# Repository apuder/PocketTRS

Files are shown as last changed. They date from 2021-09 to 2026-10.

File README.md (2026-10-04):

# PocketTRS

PocketTRS uses a modern microcontroller to emulate a TRS-80 personal computer. It can be connected to any compatible VGA monitor and PS/2 keyboard. PocketTRS has <a href="https://github.com/apuder/TRS-IO">TRS-IO</a> embedded for full FreHD support. PocketTRS offers the following features:

1. Emulates a Model III and Model 4
2. Grafyx support
3. Cassette input (500 baud only)
4. Game sound
5. Emulates the 50-pin expansion interface
6. Integrated <a href="https://github.com/apuder/TRS-IO">TRS-IO</a>

### Firmware

The heart of PocketTRS is an ESP32-based microcontroller. The firmware can be compiled using Espressif's ESP-IDF version 6.0. First install the
<a href="https://docs.espressif.com/projects/esp-idf/en/release-v6.0/esp32/get-started/index.html">ESP-IDF toolchain</a> for your platform. Next clone the PocketTRS git repository and compile the firmware via:

```
git clone --recursive https://github.com/apuder/PocketTRS.git
cd PocketTRS
idf.py build
```

The firmware can be flashed once the ESP as well as the necessary flashing circuitry is added to the PCB as explained in the next section.

### Hardware

This repository contains the complete KiCad and Gerber files for PocketTRS. The figure below shows the various connectors:



1. VGA connector
2. PS/2 connector
3. 3.5mm audio jack
4. Micro USB power supply
5. FTDI programmer interface
6. ESP reset button
7. Z80 reset button
8. 50-pin expansion interface

The BOM contains all required parts. Soldering surface mounted components can be tricky. It is suggested to build up the PCB in a particular order and test the board along each step. PocketTRS contains some test code that helps with the diagnostics. The test code can be activated at compile-time via `idf.py menuconfig > Component config > PocketTRS > Run PocketTRS PCB tests`. When the PCB tests are activated, diagnostics will be printed to the log that can be viewed via `idf.py -p <port> monitor`. The following steps refer to PocketTRS V2.3:

| Step | Components | Comments |
|---|---|---|
| 1 | J6, U4, C4, C5, C11 | Connect power via the Micro-USB adapter. Confirm 5V on J5, pin 5. Confirm 3.3V on U1, pin 2. Disconnect power. Note: for polarized caps the dot on the silkscreen indicates the positive terminal. |
| 2 | Q2, Q3, R12, R13, R14, R15, R16, C9, C10, J5, SW1, U1 | It should be possible to flash the ESP firmware via a FTDI adapter with these components. The log should print `MCP4361 not found`. |
| 3 | U5, C8 | Log should show `MCP4361 found` and `MCP23S17 not found`. Confirm 1V on pin 1, 2V on pin 2 and 3V on pin 3 of VGA adapter. |
| 4 | U2, U3, Q1, R10, R11, R17, C6, C7 | Log should show `MCP23S17 found` and `MCP23S08 found`. Measure the voltages of the odd pins of the 50-pin connector (except pin 45). The voltages should alternate between 0V and 5V every second. Permanent 0V indicates that a pin is not properly connected. A permanent 0.7V indicates that two neighboring pins are shorted. |
| 5 | J8, R18, R19, R20, R21 | Insert a formatted SD card into the SD card reader and press the 'PTRS RST' button after booting. The log should print `SD card succefully mounted`. |
| 6 | The rest | Solder the remaining components. First add the surface mounted components followed by the various connectors. |

### Usage

Once the PocketTRS card is assembled, connect a VGA monitor, a PS/2 keyboard and optinally a speaker to the audio jack. Power up PocketTRS via the micro-USB connector. You should see the TRS-80 `Cass?` prompt on the monitor. After booting PocketTRS, the following hotkeys are available via the PS/2 keyboard:

* &lt;F4&gt;  - Enable lowercase
* &lt;F5&gt;  - PocketTRS Configuration
* &lt;F6&gt;  - Send screenshot to the printer
* &lt;F9&gt;  - Reset Z80
* &lt;ESC&gt; - TRS-80 &lt;BREAK&gt; key
* '\\'         - TRS-80 &lt;CLEAR&gt; key

Instead of a PS/2 keyboard, a Bluetooth keyboard (Bluetooth Low Energy) can be used. It is paired in the web interface
(<a href="trs-io.local">trs-io.local</a>, Settings, Bluetooth Keyboard): put the keyboard in pairing mode, press *Scan* and then *Pair*
next to the keyboard's name. From then on the keyboard connects by itself.

&lt;F5&gt; allows the configuration of various aspects of PocketTRS, including setting up Wifi credentials and TRS-IO. Once Wifi is setup, the printer interface can be accessed via <a href="trs-io.local/printer">trs-io.local/printer</a>.

Use the configuration settings to activate TRS-IO. Alternatively it is possible to connect an external TRS-IO/FreHD card via the 50-pin expansion interface. In that case make sure that the internal TRS-IO is disabled.

For game sound, simply connect a speaker to the 3.5mm audio jack. It is also possible to load programs via the cassette interface (500 baud only). At the `Cass?` prompt hit 'L', connect PocketTRS audio jack to a laptop or smartphone, type `CLOAD` or `SYSTEM` in BASIC and play the 500 Baud audio file. You should see the blinking asterick in the top right corner.

### Showcases

The video below shows PocketTRS connected to a <a href="https://github.com/lambdamikel/Talker-80">Talker/80 card</a>:

PocketTRS connected to Talker/80 (https://www.youtube.com/watch?v=__6tL8iR-zk)

The next video shows PocketTRS booting from an external FreHD. Note that PocketTRS integrates TRS-IO and therefore also is compatible with FreHD, but
for the purpose of the demo, the internal TRS-IO is disabled:

PocketTRS connected to FreHD (https://www.youtube.com/watch?v=2HQh5efB2vM)

The following video shows PocketTRS booting from a 12 MB Tandy Hard Disk 26-4152 via XROM. PocketTRS is configured to disable
the internal TRS-IO and to use XROM:

PocketTRS booting from external HD (https://www.youtube.com/watch?v=oDgECPzYius)

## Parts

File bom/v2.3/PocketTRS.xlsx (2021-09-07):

PocketTRS V2.3 BOM
 |  |  |  |  |  | Previous
Reference Designator |  | Quantity | Package | Digi-Key Part Number | Manufacturer Part Number | Digi-Key Part Number | Manufacturer Part Number
C1 | 10uf | 1 | 1206 | 1276-1853-1-ND | CL31F106ZPHNNNE | 478-10742-1-ND | TAJA106K006SNJ | Changed to Ceramic / Non-Polarized
C2 | 10uf | 1 | 1206 | 1276-1853-1-ND | CL31F106ZPHNNNE | 478-10742-1-ND | TAJA106K006SNJ | Changed to Ceramic / Non-Polarized
C3 | 100n | 1 | 0805 | 399-9158-1-ND | C0805C104Z3VACTU
C4 | 100uf | 1 | 1206 | 1276-1782-1-ND | CAP CER 100UF 6.3V X5R 1206 | 478-8152-1-ND | F930J107KAA | Changed to Ceramic / Non-Polarized
C5 | 100uf | 1 | 1206 | 1276-1782-1-ND | CAP CER 100UF 6.3V X5R 1206 | 478-8152-1-ND | F930J107KAA | Changed to Ceramic / Non-Polarized
C6 | 100n | 1 | 0805 | 399-9158-1-ND | C0805C104Z3VACTU
C7 | 100n | 1 | 0805 | 399-9158-1-ND | C0805C104Z3VACTU
C8 | 100n | 1 | 0805 | 399-9158-1-ND | C0805C104Z3VACTU
C9 | 100n | 1 | 0805 | 399-9158-1-ND | C0805C104Z3VACTU
C10 | 100n | 1 | 0805 | 399-9158-1-ND | C0805C104Z3VACTU
C11 | 10uf | 1 | 1206 | 1276-1853-1-ND | CL31F106ZPHNNNE |  |  | New
C12 | 1uf | 1 | 1206 | 1276-1783-1-ND | CL31B105KOFNNNE |  |  | New
Q1 | BSS138 | 1 | SOT-23-3 | BSS138CT-ND | BSS138
Q2 | MMBT3904 | 1 | SOT-23-3 | MMBT3904-FDICT-ND | MMBT3904-7-F
Q3 | MMBT3904 | 1 | SOT-23-3 | MMBT3904-FDICT-ND | MMBT3904-7-F
R4 | 2K | 1 | 0805 | 311-2.00KCRCT-ND | RC0805FR-072KL
R5 | 2K | 1 | 0805 | 311-2.00KCRCT-ND | RC0805FR-072KL
R6 | 4K7 | 1 | 0805 | 311-4.70KCRCT-ND | RC0805FR-074K7L
R7 | 4K7 | 1 | 0805 | 311-4.70KCRCT-ND | RC0805FR-074K7L
R8 | 270R | 1 | 0805 | RHM270KCT-ND | ESR10EZPJ271
R9 | 150R | 1 | 0805 | RNCP0805FTD150RCT-ND | RNCP0805FTD150R
R10 | 10K | 1 | 0805 | 311-10.0KCRCT-ND | RC0805FR-0710KL
R11 | 10K | 1 | 0805 | 311-10.0KCRCT-ND | RC0805FR-0710KL
R12 | 4K7 | 1 | 0805 | 311-4.70KCRCT-ND | RC0805FR-074K7L
R13 | 4K7 | 1 | 0805 | 311-4.70KCRCT-ND | RC0805FR-074K7L
R14 | 12K | 1 | 0805 | A129762CT-ND | CRGCQ0805F12K
R15 | 12K | 1 | 0805 | A129762CT-ND | CRGCQ0805F12K
R16 | 4K7 | 1 | 0805 | 311-4.70KCRCT-ND | RC0805FR-074K7L
R17 | 10K | 1 | 0805 | 311-10.0KCRCT-ND | RC0805FR-0710KL
R18 | 10K | 1 | 0805 | 311-10.0KCRCT-ND | RC0805FR-0710KL
R19 | 10K | 1 | 0805 | 311-10.0KCRCT-ND | RC0805FR-0710KL
R20 | 10K | 1 | 0805 | 311-10.0KCRCT-ND | RC0805FR-0710KL
R21 | 10K | 1 | 0805 | 311-10.0KCRCT-ND | RC0805FR-0710KL
U1 | ESP32-WROVER-B | 1 |  | 1904-1034-1-ND | ESP32-WROVER-B (8MB)
U2 | MCP23S17 | 1 | SSOP | MCP23S17T-E/SSCT-ND | MCP23S17T-E/SS
U3 | MCP23S08 | 1 | SSOP | MCP23S08T-E/SSCT-ND | MCP23S08T-E/SS
U4 | AMS1117-3.3 | 1 | SOT-223-4 | LM1117MPX-3.3/NOPBCT-ND | LM1117MPX-3.3/NOPB
U5 | MCP4341 | 1 | TSSOP | MCP4361-502E/ST-ND | MCP4361-502E/ST
J1 | 2x25 Pin Header | 1 |  | ED10530-ND | 302-S501
J2 | Audio Jack 3.5mm | 1 |  | CP1-3535NG-BE-ND | SJ1-3535NG-BE |  | https://www.aliexpress.com/item/32813088425.html | Changed to DigiKey Part
J3 | Mini-DIN-6 | 1 |  | 5749180-1-ND | 5749180-1 |  | https://www.aliexpress.com/item/32761830818.html | Changed to DigiKey Part
J4 | DB15F | 1 |  | 609-5180-ND | ICD15S13E4GV00LF |  | https://www.aliexpress.com/item/32826749496.html | Changed to DigiKey Part
J5 | 1x06 Pin Header | 1 | 3M9457-36-ND | 961136-6404-AR
J6 | USB-Micro | 1 |  | 609-4616-1-ND | 10118193-0001LF |  | https://www.aliexpress.com/item/32700714989.html | Changed to DigiKey Part
J7 | Edge Connector | 0
J8 | Micro SD Card Socket | 1 |  |  |  |  | https://www.aliexpress.com/item/32906952129.html
SW1 | Pushbutton | 1 |  | 450-1650-ND | 1825910-6 |  | https://www.aliexpress.com/item/32710764066.html | Changed to DigiKey Part
SW2 | Pushbutton | 1 |  | 450-1650-ND | 1825910-6 |  | https://www.aliexpress.com/item/32710764066.html | Changed to DigiKey Part
 | USB TTL UART Module | 1 |  |  |  |  | https://www.aliexpress.com/item/32717057832.html

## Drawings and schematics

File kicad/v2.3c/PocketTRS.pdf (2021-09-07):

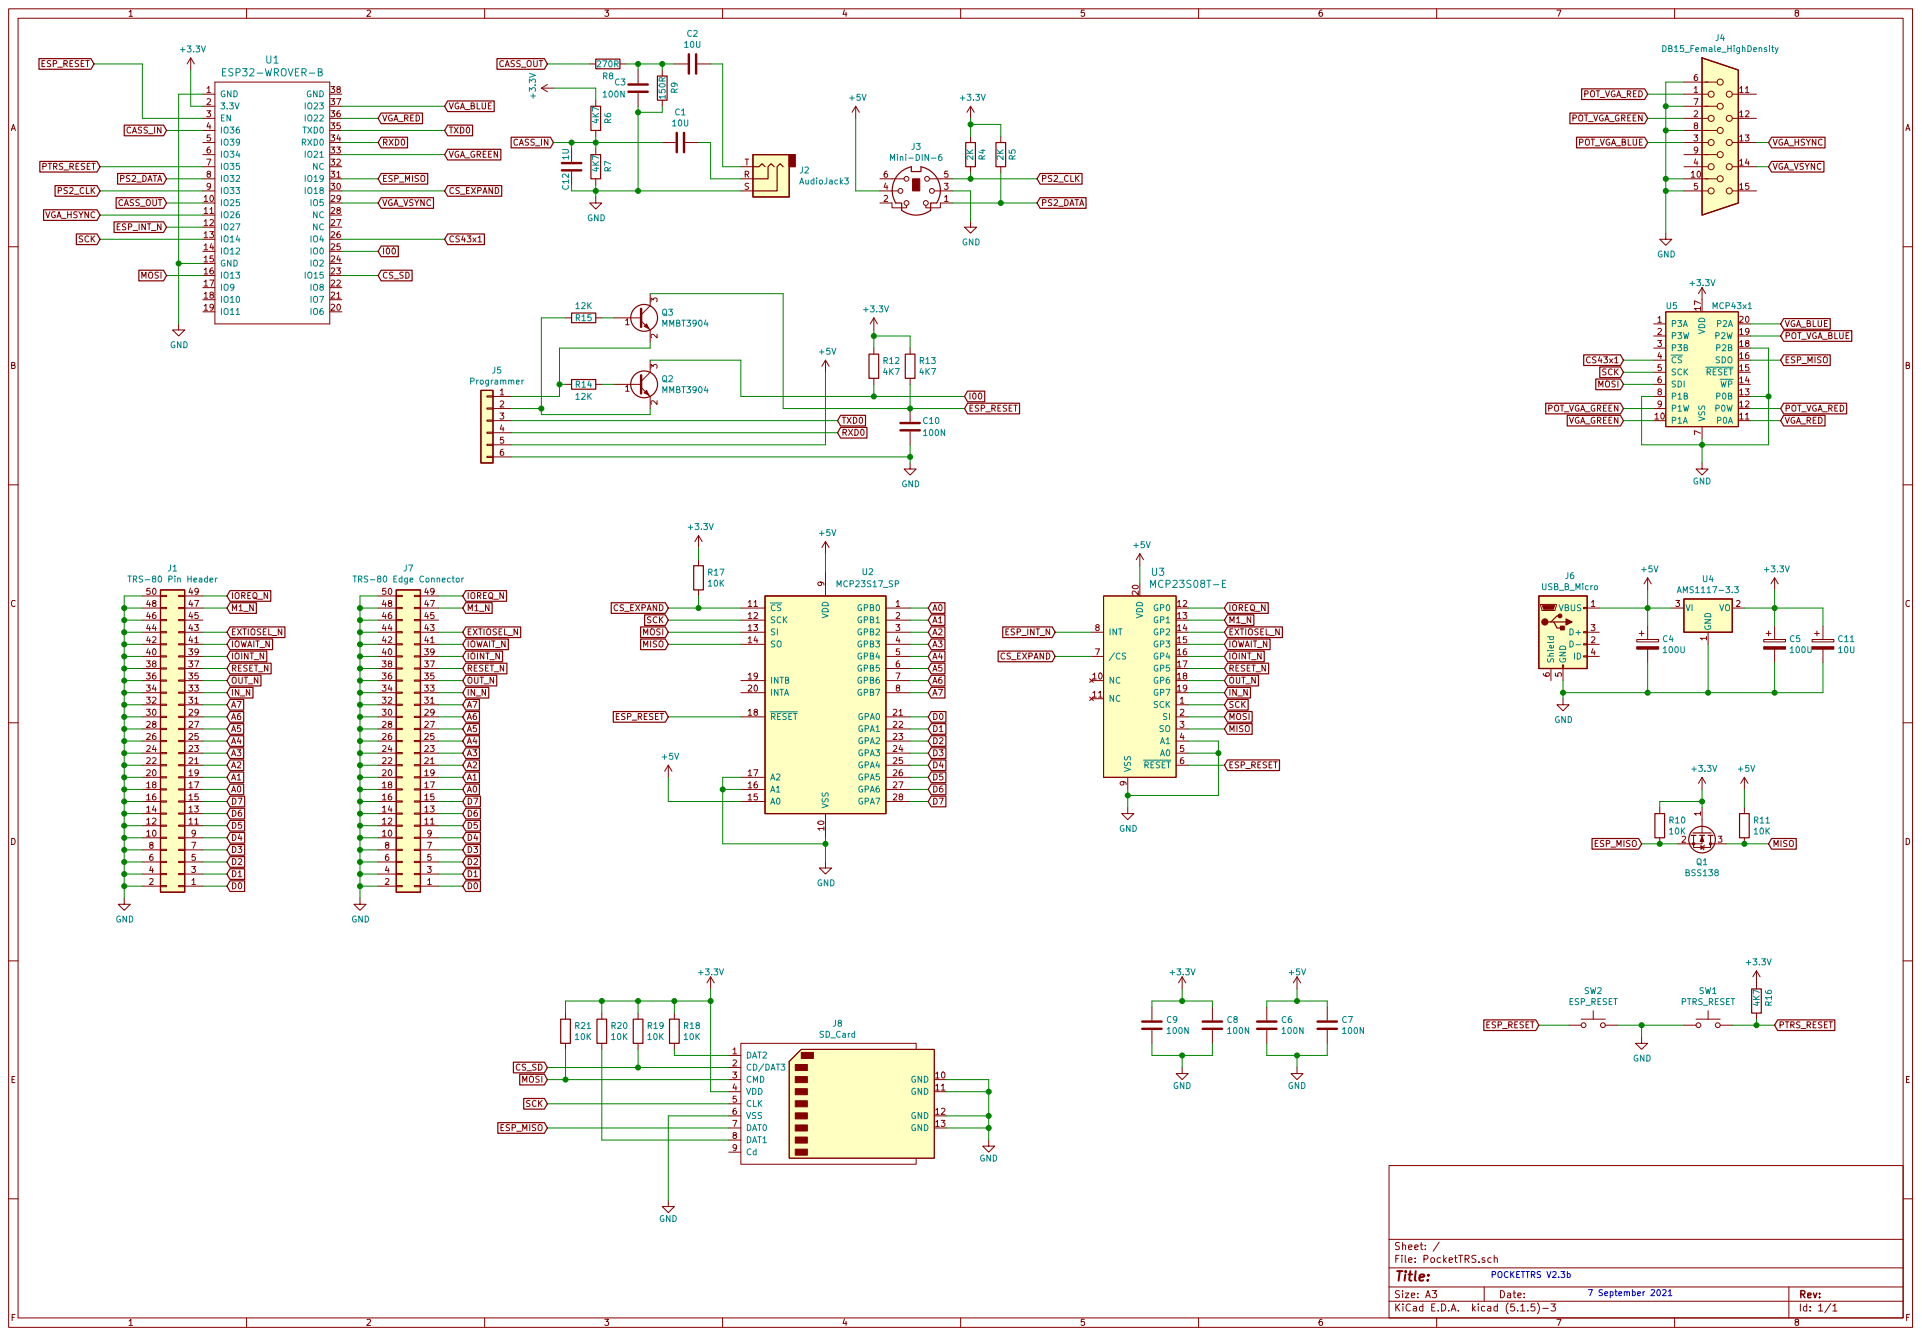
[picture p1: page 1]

34 | 33
32 | 31

28 | 27
26 | 25
24 | 23
22 | 21

18 | 17
16 | 15
14 | 13
12 | 11

Id: 1/1 Title: File: PocketTRS.sch Sheet: /

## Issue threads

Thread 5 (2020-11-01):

Expand ReadMe

OzHawk, 2020-11-01:
Sorry to raise an issue, but without any sort of discussion forum (GitHubs issue not yours) it’s difficult to start a discussion about a project.

I’m interested to know more about your project.
Does it use the standard Fabgl hardware or the TTGO VGA32 version?
Does it use the WiFi to transfer files?
Does it interface to the SD card for a file system?

Cheers,
Mike

apuder, 2020-11-01:
Sorry for the sparse (i.e., non-existing) documentation. We'll work on that soon. To answer your question: we are using the FabGL library, but we have custom hardware (i.e., we are not using the FabGL reference boards). We use an ESP-WROVER-B module that has built-in Wifi. You have access to TCP sockets from within the TRS emulation and you can also read/write files from a mounted SMB share. But we do not support SD cards (we use SMB shares instead). You can check the "kicad" folder for the schematics and Gerber files.

OzHawk, 2020-11-01:
Thanks Arno.
I was hoping for an image of the schematic, so I don’t have to install Kicad to view it.  I was interested to see what pins you have assigned to the various functions, and whether my FabGL boards will be compatible, or whether I will need to make a new board.
Without looking at the schematics, I’m guessing you’re using the ESP32 module on its own, like on the TTGO VGA32 boards, rather than using a development board like Fabrizio used.
I know that the TTGO VGA32 board is compatible with the FabGL dev board for everything except the SD card.

apuder, 2020-11-02:
Send me a private message and I'll reply with a PDF of the schematics.

OzHawk, 2020-11-02:
Sorry Arno, but I'm not sure what address to send a message to.  GitHub doesn't seem to have a Private Messaging system.

Closed 2020-11-01.

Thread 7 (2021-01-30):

Which gerber should I use?

johnddias, 2021-01-30:
Hi Arno, saw you present on Trash Talk Live and want to build one. Which grb file(s) do I need to use for the fab order?

apuder, 2021-01-30:
Please hold off for now. @jaquinn will soon push updated Gerber files. Just watch commits on this repo.

apuder, 2021-01-31:
John: it seems there was a real-live race condition: Andrew updated the PCB while I was typing my last comment. You could be able to ZIP up the v2.2 directory and submit it to your preferred fab. Please let us know if you run into problems.

johnddias, 2021-01-31:
Fantastic, thanks so much for this awesome project!

Closed 2021-01-30.

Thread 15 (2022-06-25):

Build Warnings and Errors

OzHawk, 2022-06-25:
**Building "Master" branch of PocketTRS in Linux Mint**

Installed and built according to apuder/PocketTRS/Readme.md and ESP32 release-v4.2, up to and including "Set 4: Setup the Environment Variables"

Build log contains multiple warnings, most I believe can be ignored.  Is there something about my setup that is causing these to be reported?

The build failed at the Linking stage due to multiple definitions of MD5Init, MD5Update, MD5Final.

[BuildLog-Mike(22-06-25).txt](https://github.com/apuder/PocketTRS/files/8983954/BuildLog-Mike.22-06-25.txt)

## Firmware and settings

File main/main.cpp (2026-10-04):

#include "fabgl.h"
#include "trs.h"
#include "trs-keyboard.h"
#include "trs_screen.h"
#include "i2s.h"
#include "cassette.h"
#include "io.h"
#include "ui.h"
#include "settings.h"
#include "splash.h"

#include "button.h"
#include "led.h"
#include "wifi.h"
#include "event.h"
#include "trs_io_host.h"
#include "bluetooth.h"
#include "freertos/task.h"

#include "trs-io.h"
#include "trs-fs.h"
#include "ntp_sync.h"


fabgl::PS2Controller  PS2Controller;

// The phosphor color picked in TRS-IO's web UI. Called from the web server's
// task; TRS-IO has already stored its copy.
static void apply_web_screen_color(uint8_t color)
{
  if (color <= SCREEN_COLOR_AMBER) {
    settingsScreen.setScreenColor((screen_color_t) color);
  }
}

// What TRS-IO's own main loop does besides serving the Z80: once Wi-Fi is
// up, mount the SMB share and start the web server.
static void trs_io_task(void* arg)
{
  while (true) {
    trs_io_host_poll();
    vTaskDelay(250 / portTICK_PERIOD_MS);
  }
}


void setup() {
#if 1
  printf("Heap size before VGA init: %u\n", (unsigned) esp_get_free_heap_size());
  printf("DRAM size before VGA init: %u\n", (unsigned) heap_caps_get_free_size(MALLOC_CAP_INTERNAL));
#endif

  init_button();
  init_events();
  init_trs_io();
  // TRS-IO's settings (Wi-Fi, SMB share, time zone; NVS "retrostore")
  trs_io_host_init();
  init_io();
  init_i2s();
  trs_screen.init();
  // Also gives TRS-IO's web UI the current phosphor color
  init_settings();
  trs_io_host_set_screen_color_handler(apply_web_screen_color);
  show_splash();
  init_trs_fs_posix();
  // Wi-Fi, the web UI and, from trs_io_task, the SMB share
  trs_io_host_start_network();
  xTaskCreatePinnedToCore(trs_io_task, "trs-io", 6000, NULL, 1, NULL, 1);
  vTaskDelay(5000 / portTICK_PERIOD_MS);
  //settingsCalibration.setScreenOffset();
  PS2Controller.begin(PS2Preset::KeyboardPort0, KbdMode::CreateVirtualKeysQueue);
  // After VGA and Wi-Fi have taken the internal memory they need
  init_bluetooth();
  init_bluetooth_web();

  z80_reset(0);

#if 1
  printf("Heap size after VGA init: %u\n", (unsigned) esp_get_free_heap_size());
  printf("DRAM size after VGA init: %u\n", (unsigned) heap_caps_get_free_size(MALLOC_CAP_INTERNAL));
#endif
}

void loop() {
  static fabgl::VirtualKey lastvk = fabgl::VK_NONE;
  auto keyboard = PS2Controller.keyboard();

  z80_run();

  if (is_button_short_press()) {
    z80_reset();
  }

  // Keys come from the PS/2 keyboard or from a Bluetooth one (bluetooth.cpp)
  if (keyboard == nullptr) {
    return;
  }
  if (keyboard->virtualKeyAvailable()) {
    bool down;
    auto vk = keyboard->getNextVirtualKey(&down);
    //printf("VirtualKey = %s\n", keyboard->virtualKeyToString(vk));
    if (down && vk == fabgl::VK_F5 && trs_screen.isTextMode()) {
      configure_pocket_trs();
    } else if (down && vk == fabgl::VK_F9) {
      z80_reset();
    } else if (down && vk == fabgl::VK_F6) {
      trs_screen.screenshot();
    } else {
      process_key(vk, down);
    }
  }
}

extern "C" void app_main()
{
  setup();
  while (true) loop();
}

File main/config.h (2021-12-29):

#pragma once

//#define DISABLE_IO 1

// SPI
#ifdef CONFIG_POCKET_TRS_TTGO_VGA32_SUPPORT
#define SPI_PIN_NUM_MISO GPIO_NUM_2
#define SPI_PIN_NUM_MOSI GPIO_NUM_12
#define SPI_PIN_NUM_CLK GPIO_NUM_14
#else
#define SPI_PIN_NUM_MISO GPIO_NUM_19
#define SPI_PIN_NUM_MOSI GPIO_NUM_13
#define SPI_PIN_NUM_CLK GPIO_NUM_14
#endif

#define SPI_PORT_EXP_SPEED_MHZ 10
#define SPI_DIGI_POT_SPEED_MHZ 1

#define SPI_PIN_NUM_CS_MCP23X GPIO_NUM_18
#define SPI_PIN_NUM_CS_MCP4351 GPIO_NUM_4
#define SPI_PIN_NUM_INT GPIO_NUM_27


// VGA
#define VGA_RED GPIO_NUM_22
#define VGA_GREEN GPIO_NUM_21
#define VGA_BLUE GPIO_NUM_23
#define VGA_HSYNC GPIO_NUM_26
#define VGA_VSYNC GPIO_NUM_5

#define TRS_CASSETTE_IN GPIO_NUM_36

// Keyboard: GPIO 32 & 33

// Audio: 25

// Bits of MCP23008
#define TRS_IN (1 << 7)
#define TRS_OUT (1 << 6)
#define TRS_IOBUSINT (1 << 4)
#define TRS_IOBUSWAIT (1 << 3)
#define TRS_EXTIOSEL (1 << 2)
#define TRS_M1 (1 << 1)
#define TRS_IORQ (1 << 0)

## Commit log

2020-01-31 First version of KiCad schematics
    [PocketTRS.kicad_pcb, PocketTRS.sch]
2020-02-17 1. Change keyboard pullups from 5v to 3.3v
    [PocketTRS.sch]
2020-02-25 Switch I/O bus hardware emulation to MCP port expanders
2020-03-03 Switch to SPI variants for MCP port expanders
2020-04-16 Added Kicad V1 Layout
    [PocketTRS-B_Cu.gbr, PocketTRS-B_Mask.gbr, PocketTRS-B_Paste.gbr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]
2020-04-16 Revert "Added Kicad V1 Layout"
    This reverts commit e999f42db58eae0ab27af1b6476fc24879360536.
    [PocketTRS-B_Cu.gbr, PocketTRS-B_Mask.gbr, PocketTRS-B_Paste.gbr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]
2020-04-16 Remove BAK from Kicad V1 Layout
2020-06-17 Added MCP43x1 quadpot for screen color
    [PocketTRS.sch]
2020-06-22 C8/C9 to 3.3V
    [PocketTRS.sch]
2020-07-13 Change port expander config for PCB
2020-07-14 Add workaround for PS/2 pin switch
    [main.cpp]
2020-08-02 Added Kicad V2 Layout
    [PocketTRS-B_Cu.gbr, PocketTRS-B_Mask.gbr, PocketTRS-B_Paste.gbr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]
2020-08-02 Updated Kicad V2 Layout
    1. Removed Backup Files
    2. Regenerated Gerber and Drill Files
    [PocketTRS-B_Cu.gbr, PocketTRS-B_Mask.gbr, PocketTRS-B_Paste.gbr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]
2020-08-02 Kicad V2 Fixes for PS/2 Keyboard
    Changed PS2_DATA to GPIO32 and PS2_CLK to GPIO33
    [PocketTRS-B_Cu.gbr, PocketTRS-B_Mask.gbr, PocketTRS-B_Paste.gbr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]
2020-08-30 v2.1 PCB
    1. Correct U3 MCP23S08 pin assignments for TSSOP-20
    2. Add missing MOSI connection to U5 MCP4361
    3. Updated .gitignore to exclude KiCad temporary files
    [PocketTRS-B_Cu.gbr, PocketTRS-B_Mask.gbr, PocketTRS-B_Paste.gbr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]
2020-08-30 Updated Silk Screen
    1. Added labels to indicate pin 1 for U1, U2, U3 and U5.
    2. Added + to indicate orientation for C1, C2, C3 and C5
    [PocketTRS-B_Cu.gbr, PocketTRS-B_Mask.gbr, PocketTRS-B_Paste.gbr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]
2020-10-06 Remove Arduino git module
2020-10-20 Update VGA connector
    [PocketTRS.xlsx]
2021-01-04 Add support for screen calibration
    [partitions.csv]
2021-01-31 v2.2 PCB Layout
    1. Relocate ESP32 for improved antenna clearance.
    2. Additional capacitor on 3.3V @ ESP32 to reduce noise on Casssette Out when using powered speaker.
    3. Additional capacitor on Cassette In voltage divider.
    4. BOM updates to use non-polarized ceramic capacitors.
    [PocketTRS-B_Cu.gbr, PocketTRS-B_Mask.gbr, PocketTRS-B_Paste.gbr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]
2021-02-26 Fixes for ESP-IDF 4
    [config.h, spi.cpp]
2021-03-13 Reset canvas when resolution changes
    [trs_screen.cpp]
2021-03-16 Fix issue with accessing RAM beyond video memory
    [main.cpp, trs_screen.cpp]
2021-03-23 Add support for 4 MHz (but, ESP is too slow)
    [io.cpp, trs.h]
2021-04-03 Rudimentary printer interface at trs-io.local/printer
2021-04-08 Add support for physical reset button
2021-04-09 Remove screen calibration option
2021-04-29 Fix for video page bit. Screenshot support
    [io.cpp, main.cpp, trs_screen.cpp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]
2021-05-06 Fix for switching of screen mode
    [trs_screen.cpp]
2021-07-15 Initial support for the TTGO VGA32 board
2021-08-17 Fixes for latest version of TRS-IO
    [main.cpp]
2021-08-18 Restore screen color after reboot on TTGO
    [main.cpp, trs_screen.cpp]
2021-08-19 Create v2.3 PCB
    1. Adds 50 pin edge connector
    [PocketTRS-B_Cu.gbr, PocketTRS-B_Mask.gbr, PocketTRS-B_Paste.gbr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]
2021-08-24 Add SD Card to v2.3 PCB
    1. Added SD Card interface.
    2. IO Port expanders share CS line with individual addressing.
    [PocketTRS.kicad_pcb, PocketTRS.sch]
2021-08-25 Updates to v2.3 PCB
    1. Add pullup to MISO
    2. MCP43X1 connects to ESP_MISO
    3. Labels on Edge Connector
    [PocketTRS-B_Cu.gbr, PocketTRS-B_Mask.gbr, PocketTRS-B_Paste.gbr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]
2021-08-25 Updates to v2.3 PCB
    1. Update footprint definition for MicroUSB connector
    [PocketTRS.kicad_pcb]
2021-09-07 v2.3b PCB
    1. Minor change to relocate R17 to the back side of the board
    [PocketTRS-B_Cu.gbr, PocketTRS-B_Mask.gbr, PocketTRS-B_Paste.gbr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]
2021-09-07 Updated BOM for v2.3 and v2.3b
    1. Updated BOM for both v2.3 variants adding extra resistors and Micro-SD socket.
    [PocketTRS.xlsx]
2021-12-29 Fix issue with accidentally disabling hardware address for MCP23S08
    [io.cpp, spi.cpp]
2022-04-26 Update FabGL and TRS-IO. Integrate new printer interface
2022-04-29 Support multiple printer interfaces
2022-06-14 gitignore for KiCad
2022-06-14 PocketTRS 2.3c
    [PocketTRS-B_Cu.gbr, PocketTRS-B_Mask.gbr, PocketTRS-B_Paste.gbr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]
2022-06-14 Change Gerber output directory
    [PocketTRS.kicad_pcb]
2026-10-04 Port to ESP-IDF v6
    PocketTRS now builds with ESP-IDF 6.0 instead of 4.2.
    Submodules:
    - FabGL: shaeberling/FabGL (main), which builds with IDF 5/6.
    - TRS-IO: branch idf-v6, upstream master (419 commits newer than the
    previous pin) plus the IDF v6 fixes.
    Build:
    - sdkconfig.defaults on top of FabGL's sdkconfig.fabgl replaces the
    checked-in IDF 4.2 sdkconfig. The GNU make files and platformio.ini are
    gone: neither supports IDF 6.
    - Warnings are not errors (libsmb2, mongoose and TRS-IO do not build
    warning-free with GCC 15), and the C library is newlib, as before.
    - mDNS is a managed component now.
    - The app partition grows from 1.5 MB to 2 MB, and there is a 256K "html"
    SPIFFS partit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
    [partitions.csv]
2026-10-04 Make room in internal memory and IRAM
    With VGA, Wi-Fi and the web server running, 88 KB of internal memory were
    free and IRAM was 79% full. The Bluetooth stack, which comes next, needs
    about 70 KB of internal memory and 34 KB of IRAM.
    Internal memory:
    - malloc() prefers PSRAM for allocations of more than 4 KB (was 16 KB).
    - Wi-Fi buffers as in the IDF 4.2 firmware: 8 static RX, 16 dynamic RX,
    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
2026-10-04 bt_keyboard: reconnect to the paired keyboard on the ESP32
    connect_paired() opened the keyboard with the address type
    BLE_ADDR_TYPE_RPA_PUBLIC. The ESP32-S3's controller takes that; the
    ESP32's (BLE 4.2, no link layer privacy) rejects "LE Create Connection"
    with "Invalid Param", so a paired keyboard never came back:
    BT_HCI: opcode=0x200d, status= 12: Invalid Param
    BLE_HIDH: OPEN failed: 0x85
    On the ESP32, ask for the keyboard by the address type stored with the
    pairing, public or random. Other chips are unchanged.
    Tested with a Logitech Pebble Keys 2 K380s, which keeps one static random
    address per pairing.
2026-10-04 Bluetooth keyboard, paired in the web UI
    A Bluetooth (BLE) keyboard next to the PS/2 one. Its keys go into the same
    FabGL virtual key queue, so the emulator, the F5 menu and the hotkeys work
    with either. The HID reports are translated as a US keyboard.
    One keyboard can be paired. It is paired in TRS-IO's web UI (Settings,
    Bluetooth Keyboard): Scan, then Pair next to the keyboard's name; a
    keyboard that asks for a passkey gets it shown there. From then on a task
    keeps it connected: while it is not, it tries to reach it, 10 seconds at a
    time. With no keyboard paired the radio stays quiet. Unpair in the web UI
    or "Reset Settings" in the F5 menu forget the keyboard.
    - main/bluetooth.cpp: the B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
    [partitions.csv]
